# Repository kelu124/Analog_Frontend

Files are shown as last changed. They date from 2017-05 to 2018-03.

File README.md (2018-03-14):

# Analog Frontend PCB
This folder contains the design files for the analog circuitry required for a single channel of an ultrasound imaging system. 

Schematic:  
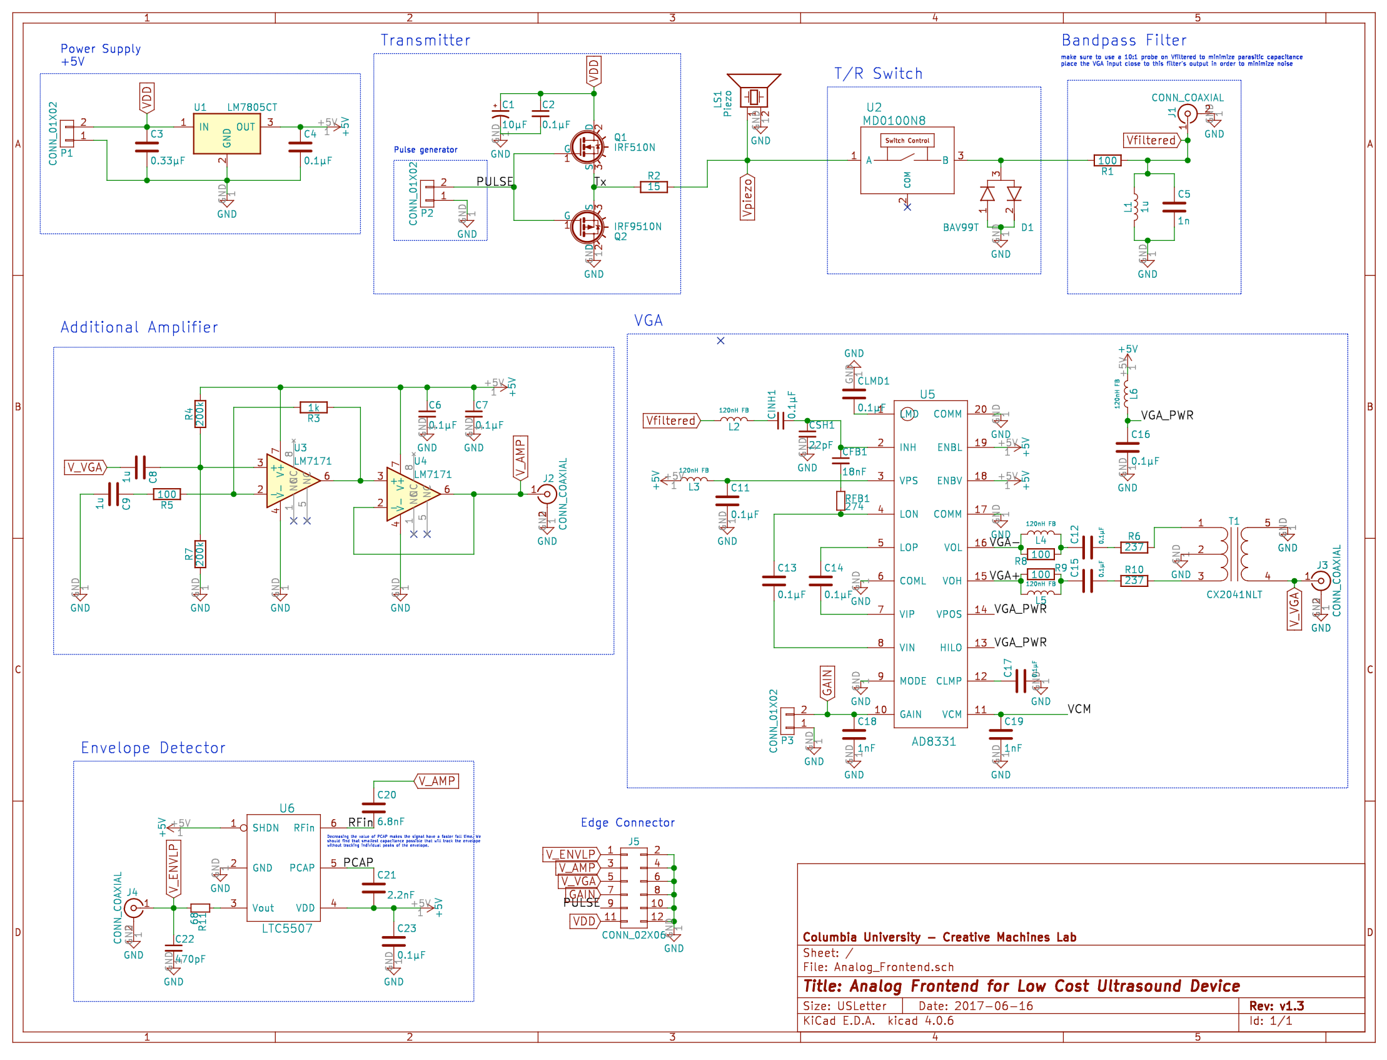
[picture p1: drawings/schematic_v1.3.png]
Schematic
  
See the `drawings` folder for a high-resolution PDF version.

PCB:  
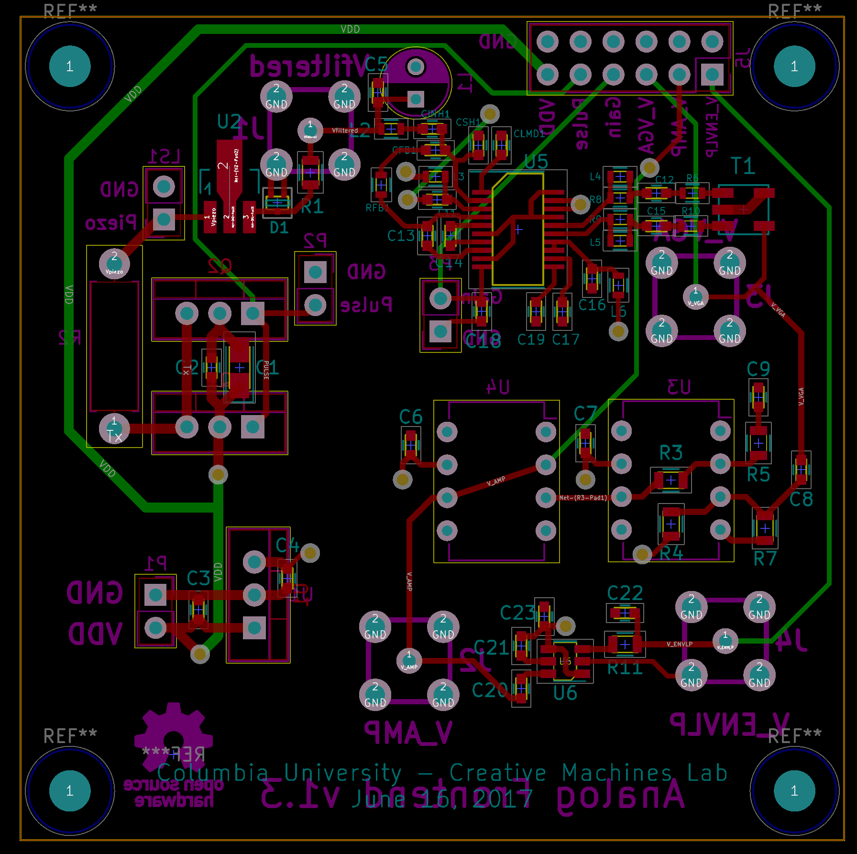
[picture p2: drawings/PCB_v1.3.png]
PCB
  
See the `drawings` folder for a full resolution PDF version, including each layer individually.

### Bill of Materials
See `Analog_Frontend.html`.

### Changelog
* `v1.0` Initial design
* `v1.1` 
* `v1.2` 
* `v1.3` Added a row of header pins and silkscreened labels
* `v1.3-doc` Added documentation
* `v2.0` Minitiarized design
* `v2.1b` Single transistor transmitter
* `v2.2_op1` Single transistor transmitter with higher output power
* `v2.2_op2` Push-pull transmitter using DMN2004K and DMP2004K MOSFETs
* `v2.2_op3` (Work in Progress) Transmitter using the MD1213 and TC6320 ultrasound transmitter chips

Each version can be accessed in this repository through the git tag system. 

### Credits
Designed by William Meng, Cindy Xiao, and Ruoyu Sheng.

The VGA subcircuit design was adapted from the [AD8331 evaluation board](http://www.analog.com/media/en/technical-documentation/evaluation-documentation/154207235AD8331EB_a.pdf). 

Community-developed KiCAD symbols and models:

* [SMA footprint](https://github.com/rascalmicro/rascalmicro-kicad-footprints.pretty/blob/master/SMA.kicad_mod)
* [SOT-523 footprint](https://github.com/cpavlina/kicad-pcblib/blob/master/smd-semi.pretty/SOT-523.kicad_mod)
* [Teensy symbols](https://github.com/XenGi/teensy_library) and [Teensy footprints](https://github.com/XenGi/teensy.pretty)

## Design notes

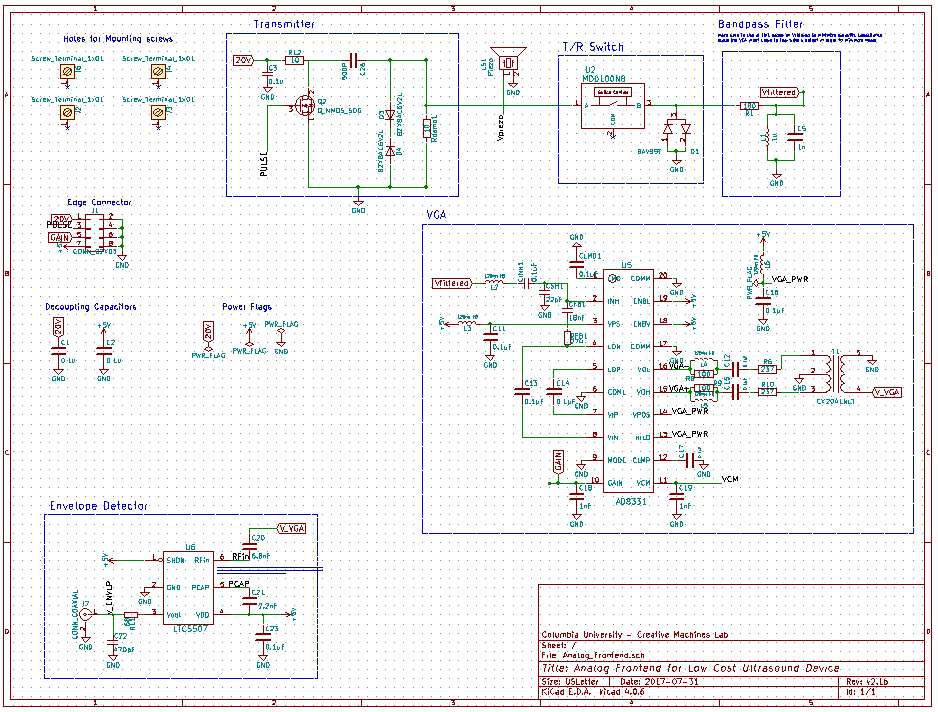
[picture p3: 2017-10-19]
drawings/schematic_v2.1b.PNG

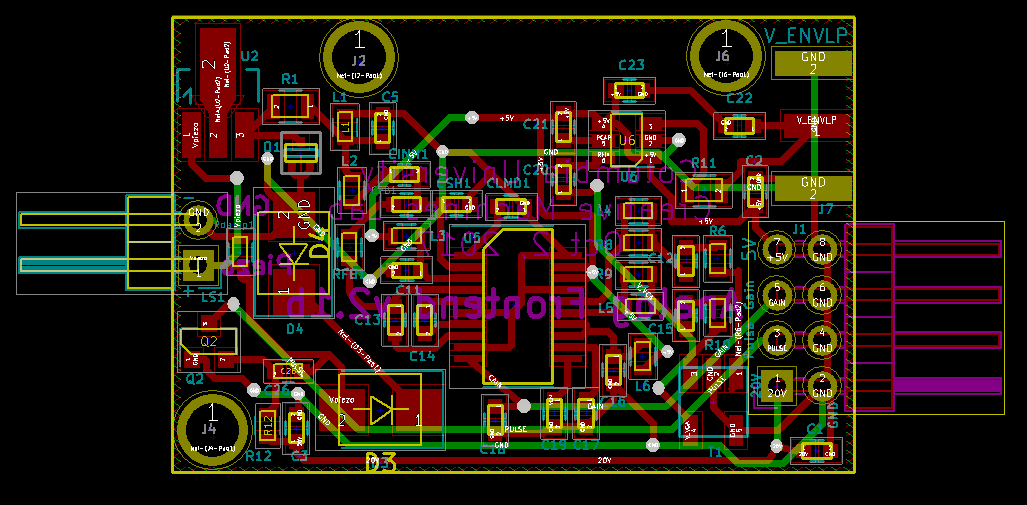
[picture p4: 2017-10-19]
drawings/PCB_v2.1b.png

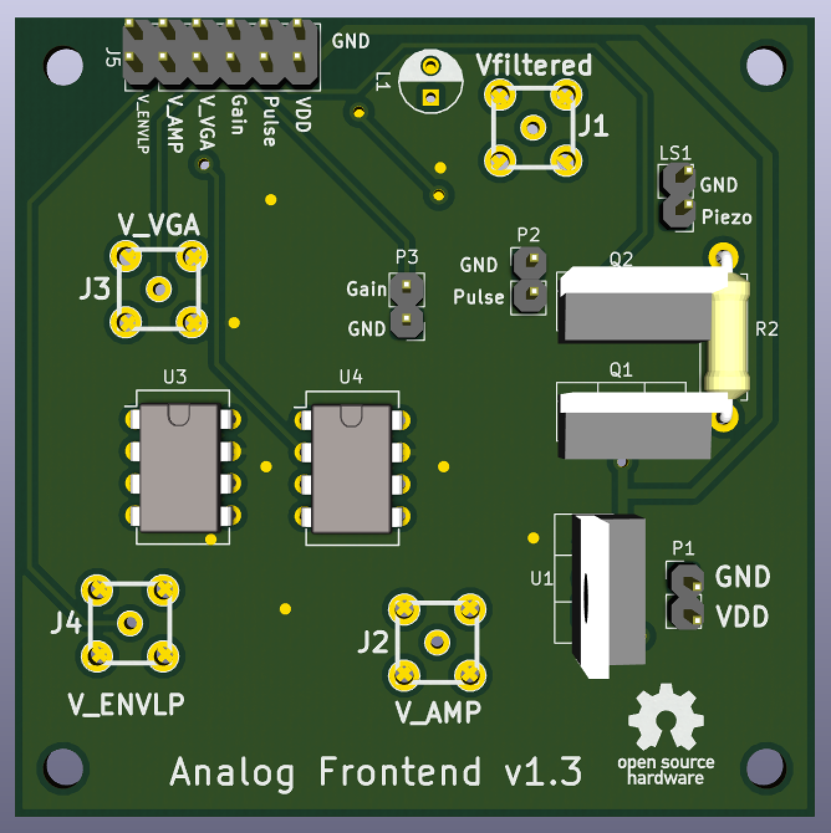
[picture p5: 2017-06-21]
drawings/PCB_back3D_v1.3.png

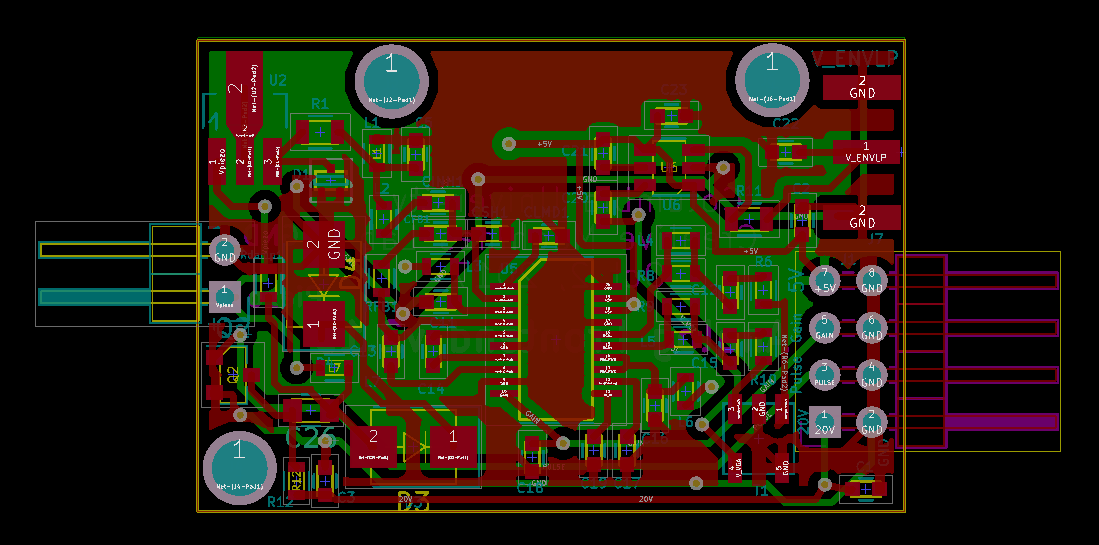
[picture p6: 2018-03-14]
drawings/PCB_v2.2_op1.png

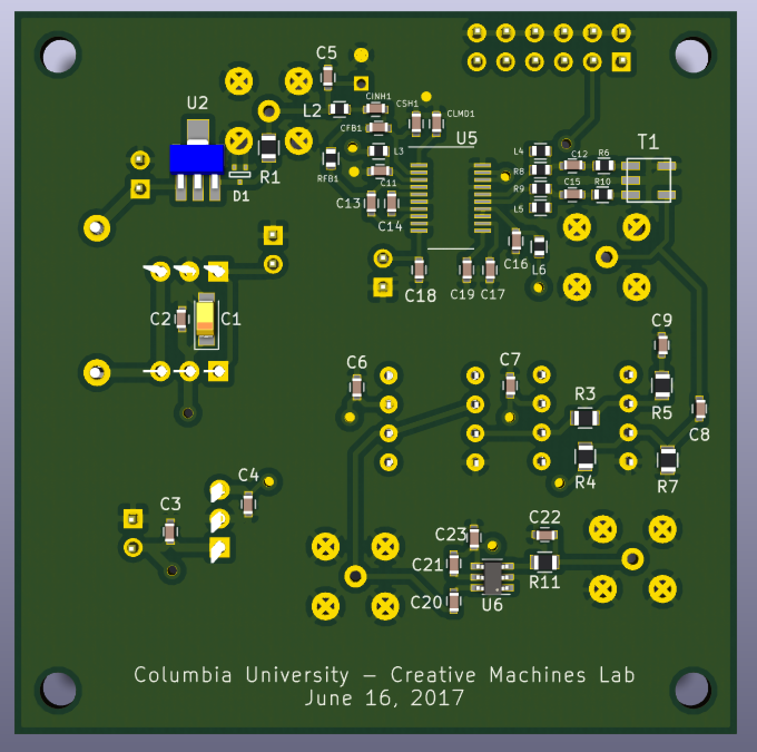
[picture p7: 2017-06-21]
drawings/PCB_front3D_v1.3.png

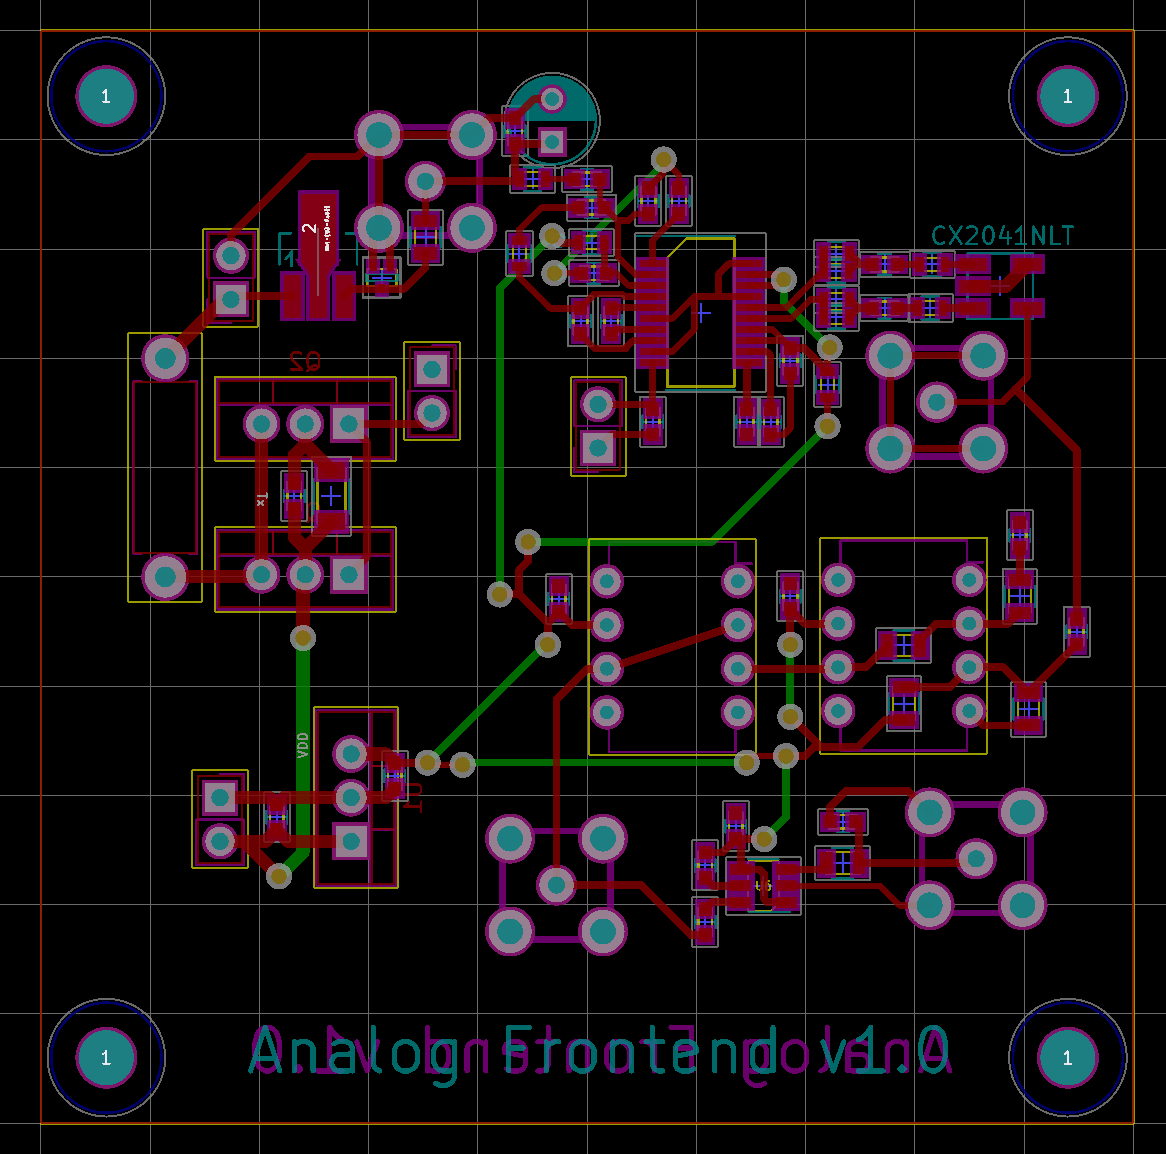
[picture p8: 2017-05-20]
drawings/PCB.png

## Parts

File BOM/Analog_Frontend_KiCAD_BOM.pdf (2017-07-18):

Ref | Qty | Value | Footprint
C5 | 1 | 1n | Capacitors_SMD:C_0603
C21 | 1 | 2.2nF | Capacitors_SMD:C_0603
C20 | 1 | 6.8nF | Capacitors_SMD:C_0603
C8 C9 | 2 | 1u | Capacitors_SMD:C_0603
C14 C13 C16 C11 C12 C15 C17 C23 C4 C2 CLMD1 CINH1 C7 C6 | 14 | 0.1ÂµF | Capacitors_SMD:C_0603
C18 C19 | 2 | 1nF | Capacitors_SMD:C_0603
C3 | 1 | 0.33ÂµF | Capacitors_SMD:C_0603
C1 | 1 | 10ÂµF | Capacitors_Tantalum_SMD:CP_Tantalum_Case- A_EIA-3216- 18_Reflow
C22 | 1 | 470pF | Capacitors_SMD:C_0603
CFB1 | 1 | 18nF | Capacitors_SMD:C_0603
CSH1 | 1 | 22pF | Capacitors_SMD:C_0603
D1 | 1 | BAV99T | custom:SOT-523
J3 J1 J4 J2 | 4 | CONN_COAXIAL | custom:SMA_uxcell
J5 | 1 | CONN_02X06 | Pin_Headers:Pin_Header_Straight_2x06_Pitch2.54mm
L1 | 1 | 1u | Capacitors_THT:C_Radial_D5_L6_P2.5
L6 L3 L2 L4 L5 | 5 | 120nH FB | Resistors_SMD:R_0603

# ANALOG FRONTEND FOR LOW COST ULTRASOUND DEVICE BOM REV V1.3

DATE

2017-06-16

COMPANY

Columbia University - Creative Machines Lab

COMMENT 1 | COMMENT 2
COMMENT 3 | COMMENT 4 | TOTAL PARTS
| | 63 (Unique 34)

# [C] - Capacitors

# [CFB] -

# [CSH] -

# [D] - Diodes

[J] -

# [L] - Inductors

LS1 | 1 | Piezo | Pin_Headers:Pin_Header_Straight_1x02_Pitch2.54mm
P2 P1 P3 | 3 | CONN_01X02 | Pin_Headers:Pin_Header_Straight_1x02_Pitch2.54mm
Q1 | 1 | IRF510N | TO_SOT_Packages_THT:TO- 220_Vertical
Q2 | 1 | IRF9510N | TO_SOT_Packages_THT:TO- 220_Vertical
R2 | 1 | 15 | Resistors_THT:R_Axial_DIN0411_L9.9mm_D3.6mm_P12.70mm_Horizontal
R1 R5 | 2 | 100 | Resistors_SMD:R_0805
R4 R7 | 2 | 200k | Resistors_SMD:R_0805
R3 | 1 | 1k | Resistors_SMD:R_0805
R8 R9 | 2 | 100 | Resistors_SMD:R_0603
R6 R10 | 2 | 237 | Resistors_SMD:R_0603
R11 | 1 | 68 | Resistors_SMD:R_0805
RFB1 | 1 | 274 | Resistors_SMD:R_0603
T1 | 1 | CX2041NLT | custom:CX2041NLT
U6 | 1 | LTC5507 | custom:TSOT-23- 6_MK06A
U5 | 1 | AD8331 | custom:QSOP- 20_3.9x8.6mm_Pitch0.64mm
U1 | 1 | LM7805CT | TO_SOT_Packages_THT:TO- 220_Vertical
U3 U4 | 2 | LM7171 | Housings_DIP:DIP- 8_W7.62mm
U2 | 1 | MD0100N8 | TO_SOT_Packages_SMD:SOT89- 3_Housing_Handsoldering

[LS] -

# [P] - Connectors

# [Q] - Transistors

# [R] - Resistors

# [RFB] -

[T] -

# [U] - Semiconductors

BOM made with KICAD_BOM_WIZARD (Generated Tuesday, July 18, 2017 'AMt' 11:46:00 AM)

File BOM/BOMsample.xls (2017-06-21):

Mfg Part # | Ref Des | Manufacturer | Dist. Part # | Qty | Description
06031C102KAT2A | C5,C18，C19 | AVX Corporation | 478-1199-1-ND | 3 | CAP CER 1000PF 100V X7R 0603
C0603C682F3GACTU | C20 | KEMET | 399-11154-2-ND | 1 | CAP CER 6800PF 25V C0G/NP0 0603
0603ZC105JAT2A | C8C9 | AVX Corporation | 478-10074-2-ND | 2 | CAP CER 1UF 10V X7R 0603
06035C104KAZ2A | C14，C13，C16，C11，C12，C15，C17,C23，C4，C2，CLMD1.C1NH1，C7，C6 | AVX Corporation | 478-3540-1-ND | 14 | CAP CER 0.1UF 50V X7R 0603
C1608X7R1H334K080AC | C3 | TDK Corporation | 445-5950-1-ND | 1 | CAP CER 0.33UF 50V X7R 0603
F931A106MAA | C1 | AVX Corporation | 478-8193-1-ND | 1 | CAP TANT 10UF 10V 20% 1206
C1608C0G1H471F080AA | C22 | TDK Corporation | 445-5370-2-ND | 1 | CAP CER 470PF 50V C0G 0603
C0603C183K5RACTU | CFB1 | KEMET | 399-7868-1-ND | 1 | CAP CER 0.018UF 50V X7R 0603
06035A220JAT2A | CSH1 | AVX Corporation | 478-1167-1-ND | 1 | CAP CER 22PF 50V C0G/NP0 0603
BAV99T-7-F | D1 | Diodes Incorporated | BAV99T-FDICT-ND | 1 | DIODE ARRAY GP 85V 75MA SOT523
BLM18BA750SN1D | L2 L3 L4 L5 L6 | Murata Electronics North America | 490-1018-1-ND | 5 | FERRITE BEAD 75 OHM 0603 1LN
RC0805FR-07100RL | R1 R5 | Yageo | 311-100CRTR-ND | 2 | RES SMD 100 OHM 1% 1/8W 0805
RC0805FR-07200KL | R4 R7 | Yageo | 311-200KCRTR-ND | 2 | RES SMD 200K OHM 1% 1/8W 0805
RC0805FR-071KL | R3 | Yageo | 311-1.00KCRTR-ND | 1 | RES SMD 1K OHM 1% 1/8W 0805
CRG0603F100R | R8 R9 | TE Connectivity Passive Product | A106047CT-ND | 2 | RES SMD 100 OHM 1% 1/10W 0603
ERJ-3EKF2370V | R6 R10 | Panasonic Electronic Components | P237HCT-ND | 2 | RES SMD 237 OHM 1% 1/10W 0603
RC0805FR-0768RL | R11 | Yageo | 311-68.0CRTR-ND | 1 | RES SMD 68 OHM 1% 1/8W 0805
ERJ-3EKF2740V | RFB1 | Panasonic Electronic Components | P274HCT-ND | 1 | RES SMD 274 OHM 1% 1/10W 0603
CX2041NLT | T1 | Pulse Electronics Corporation | 553-2290-2-ND | 1 | TRANSFORMER FOR WIDEBAND RF APP
LTC5507ES6#TRMPBF | U6 | Linear Technology | LTC5507ES6#TRMPBFCT-ND | 1 | IC DETEC RF 100KHZ-1GHZ TSOT23-6
AD8331ARQZ-R7 | U5 | Analog Devices |  | 1 | SP Amp Variable Gain Amp Single 5.5V 20-Pin QSOP T/R
MD0100N8-G | U2 | Microchip Technology | MD0100N8-GCT-ND | 1 | IC PWM MGMT SUPERVISOR SOT89-3
GRM1885C1H222FA01D | C21 | Murata Electronics North America | 490-7768-2-ND | 1 | CAP CER 2200PF 50V C0G/NP0 0603
11R102C | L1 | Murata Power Solutions Inc. | 811-2018-ND | 1 | FIXED IND 1UH 3A 20 MOHM TH
IRF510PBF | Q1 | Vishay Siliconix | IRF510PBF-ND | 1 | MOSFET N-CH 100V 5.6A TO-220AB
IRF9510PBF | Q2 | Vishay Siliconix | IRF9510PBF-ND | 1 | MOSFET P-CH 100V 4A TO-220AB
CF14JT15R0 | R2 | Stackpole Electronics Inc. | CF14JT15R0TR-ND | 1 | RES 15 OHM 1/4W 5% AXIAL
LM7805ACT | U1 | Fairchild/ON Semiconductor | LM7805ACT-ND | 1 | IC REG LDO 5V 1A TO220-3
LM7171BIN/NOPB | U3 U4 | Texas Instruments | LM7171BIN/NOPB-ND | 2 | IC OPAMP VFB 200MHZ 8DIP
 | J1, J2, J3, J4 |  |  | 4 | JUMP

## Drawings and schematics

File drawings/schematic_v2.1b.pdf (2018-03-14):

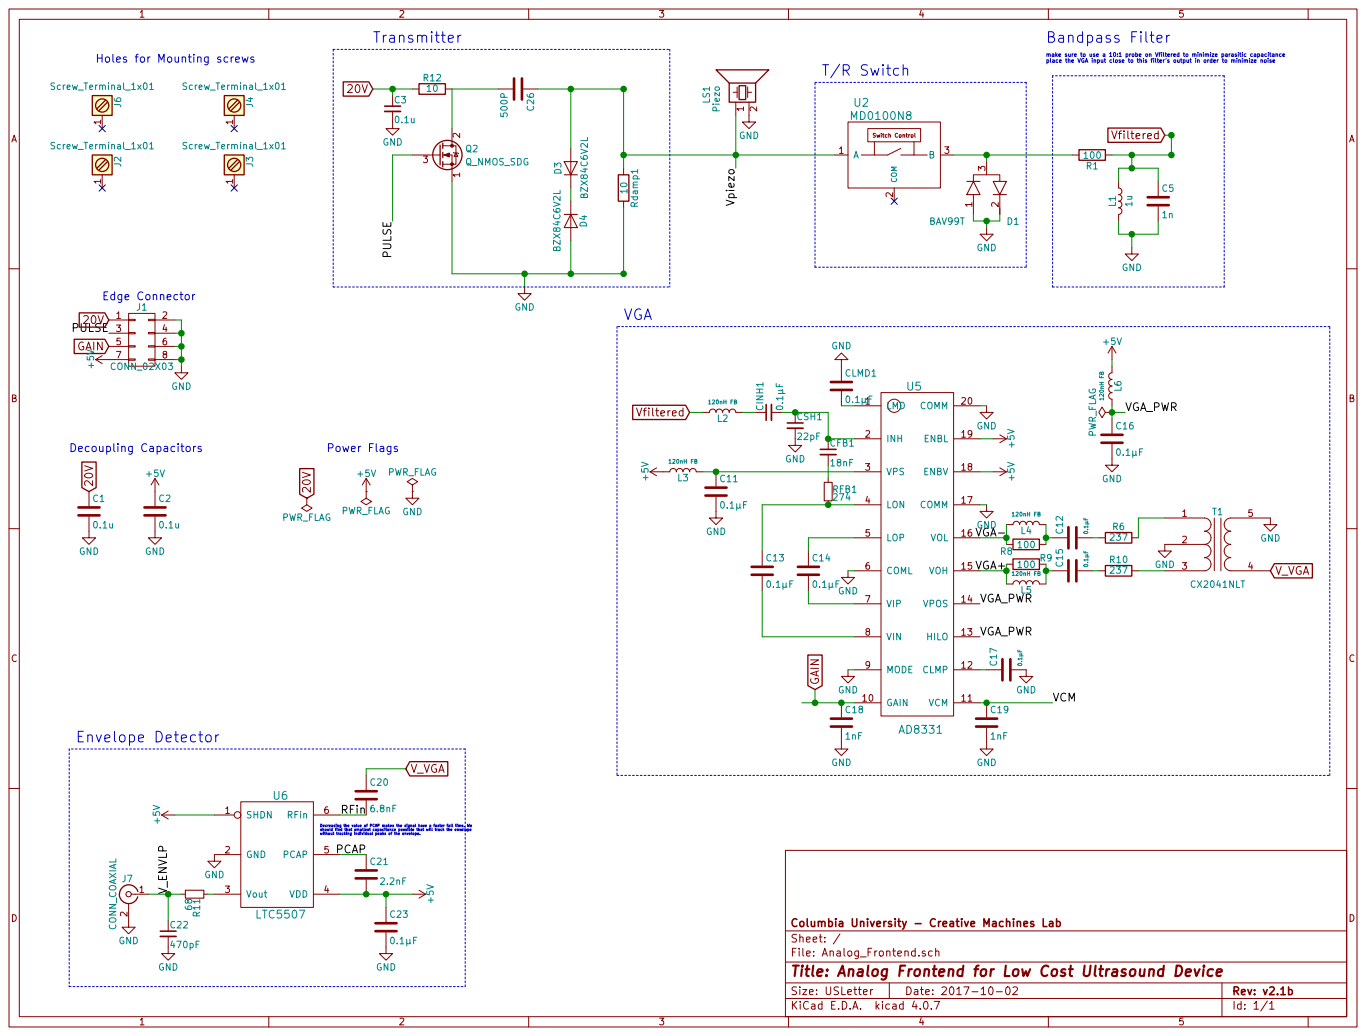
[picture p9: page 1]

make sure to use a 10:1 probe on Vfiltered to minimize parasitic capacitance
place the VGA input close to this filter's output in order to minimize noise

Decreasing the value of PCAP makes the signal have a faster fall time. We should find that smallest capacitance possible that will track the envelope without tracking individual peaks of the envelope. PULSE
GAIN

File: Analog_Frontend.sch Sheet: / Columbia University - Creative Machines Lab

Id: 1/1 Title: Analog Frontend for Low Cost Ultrasound Device

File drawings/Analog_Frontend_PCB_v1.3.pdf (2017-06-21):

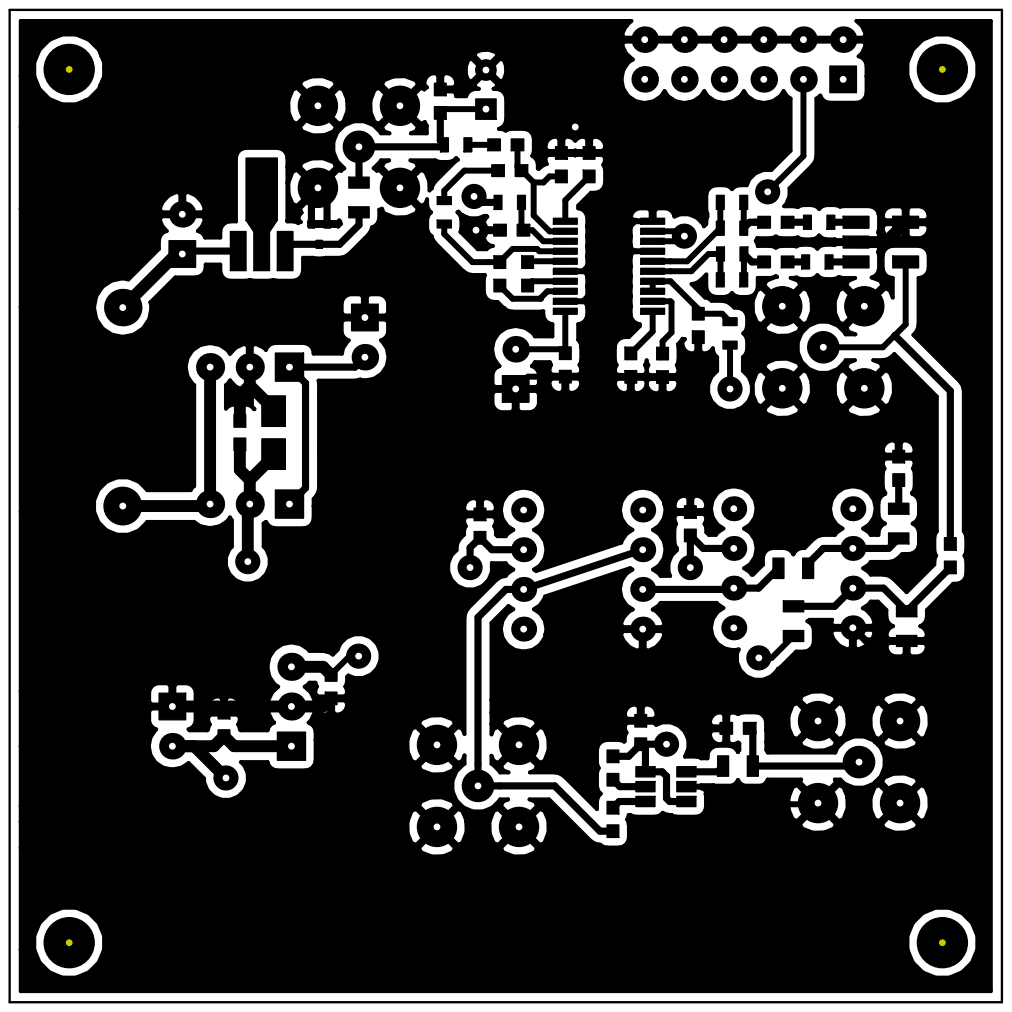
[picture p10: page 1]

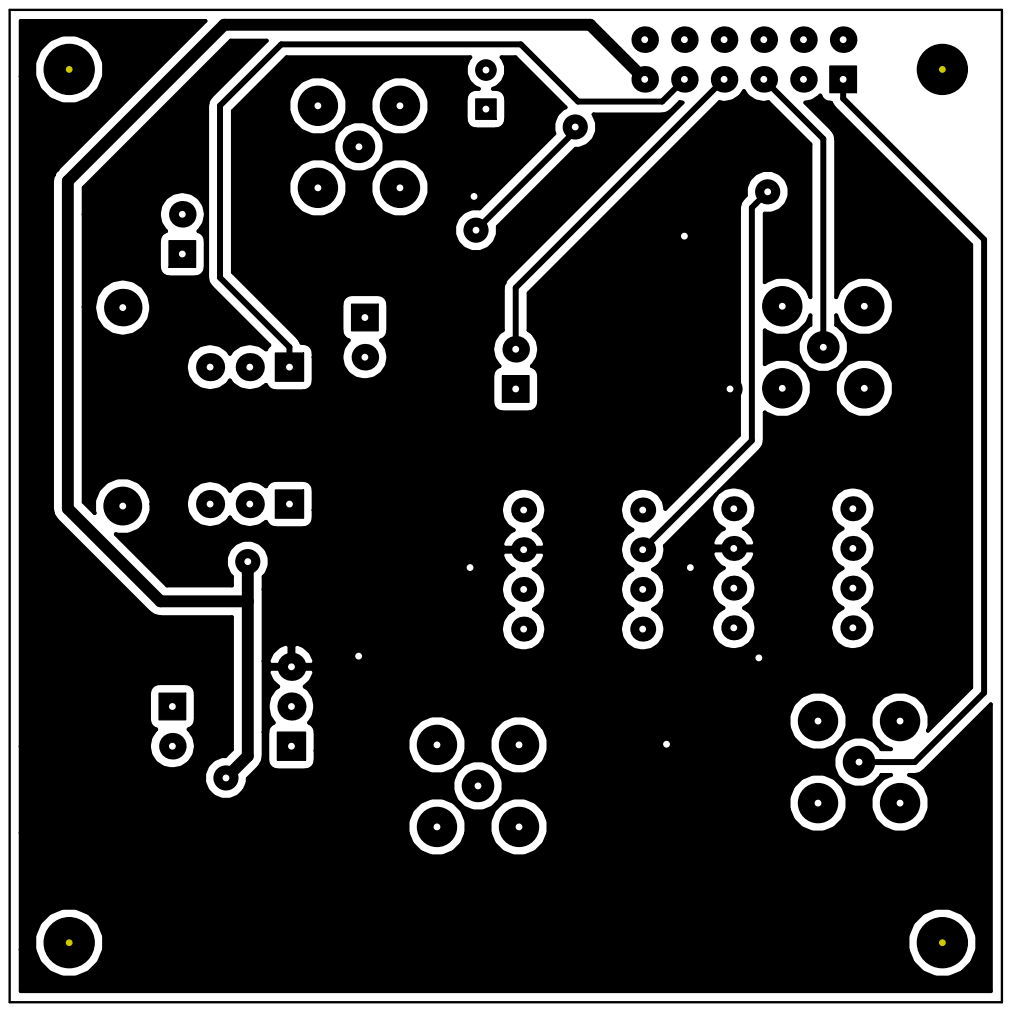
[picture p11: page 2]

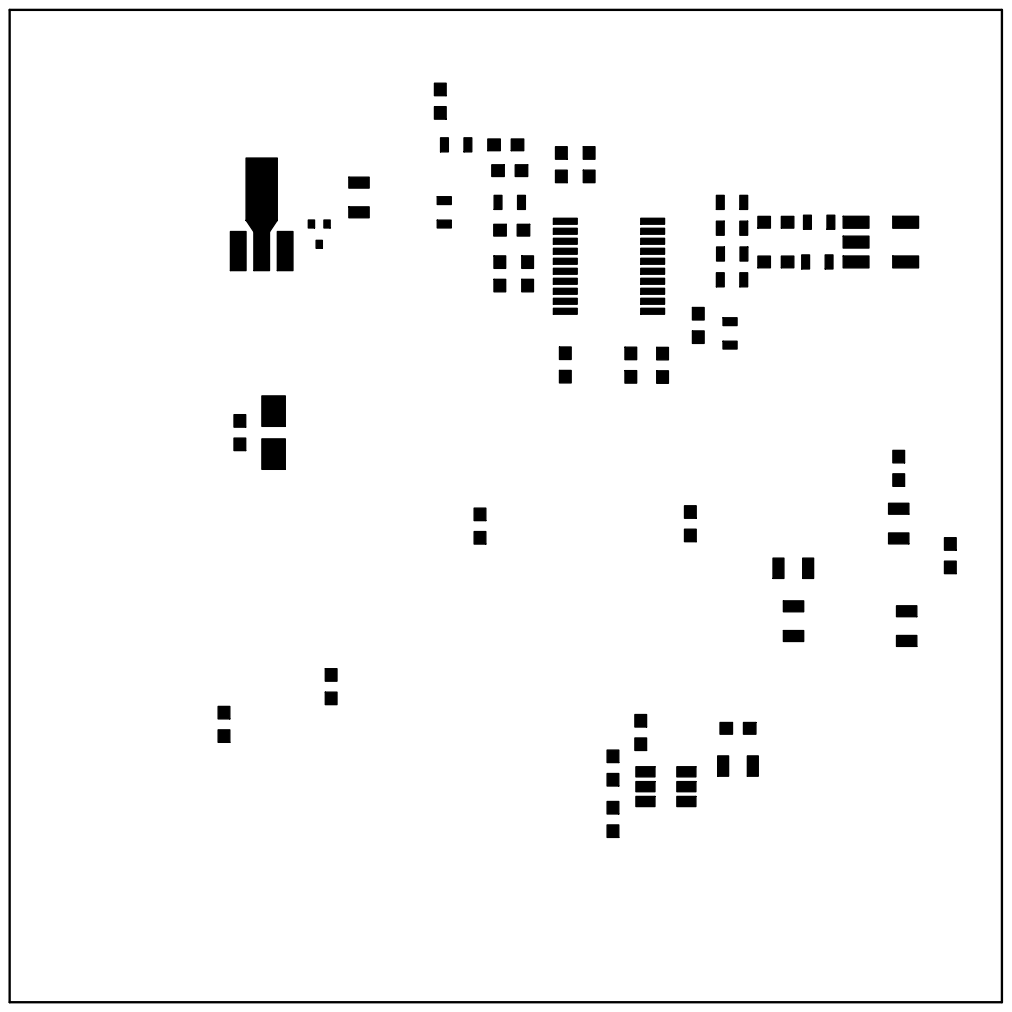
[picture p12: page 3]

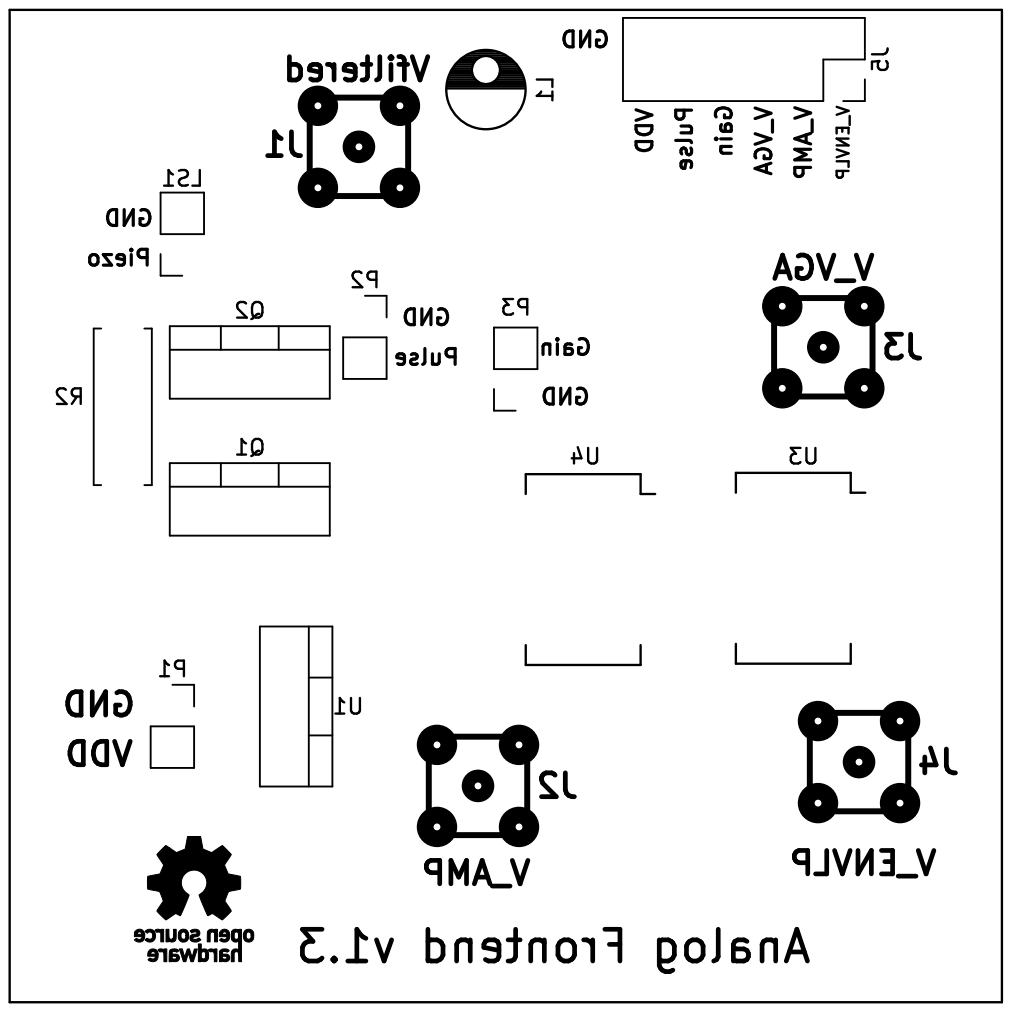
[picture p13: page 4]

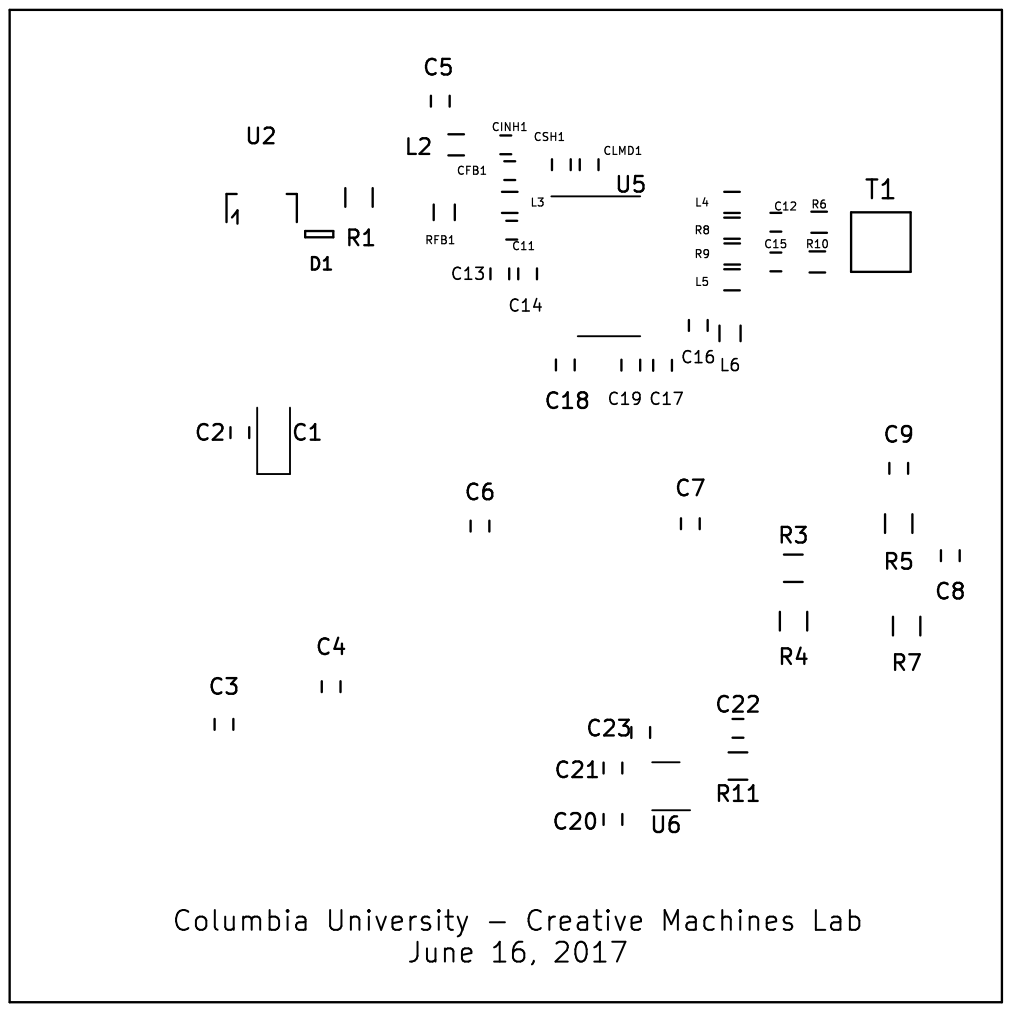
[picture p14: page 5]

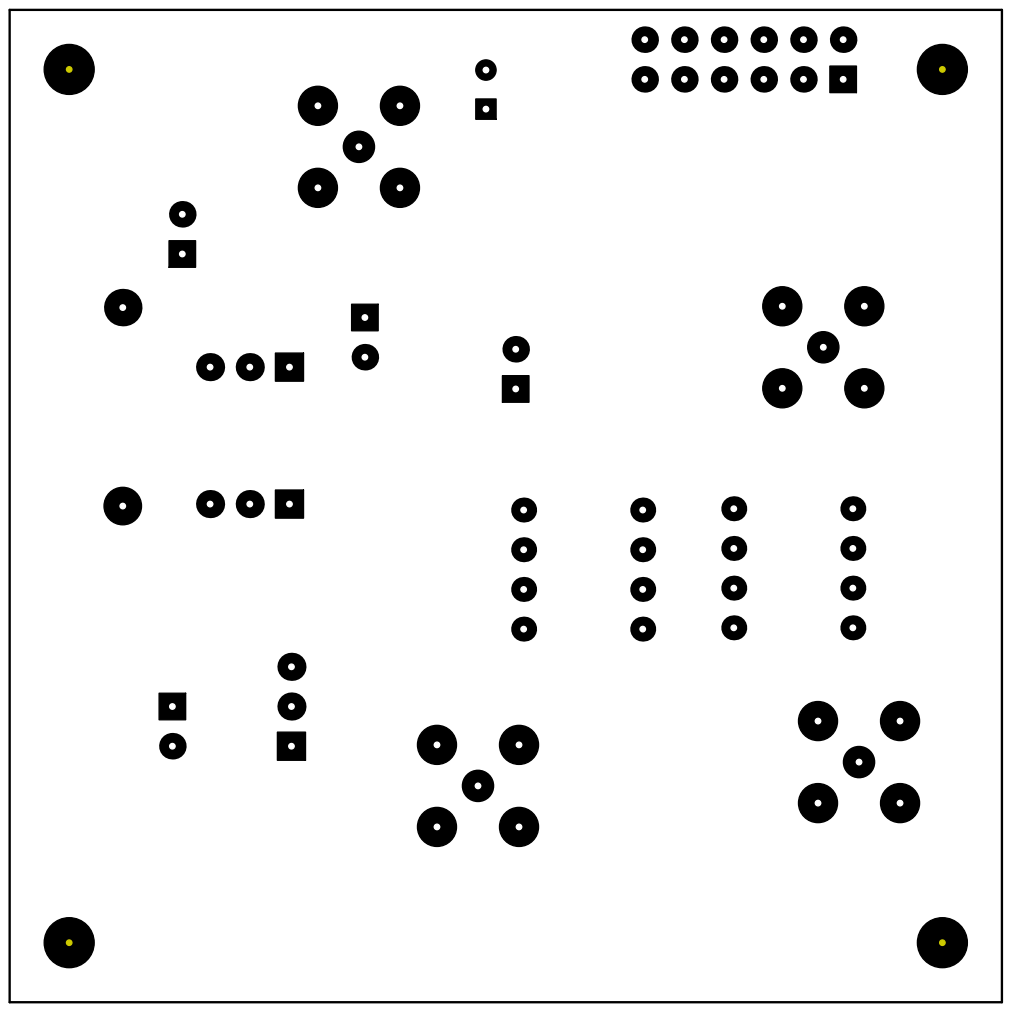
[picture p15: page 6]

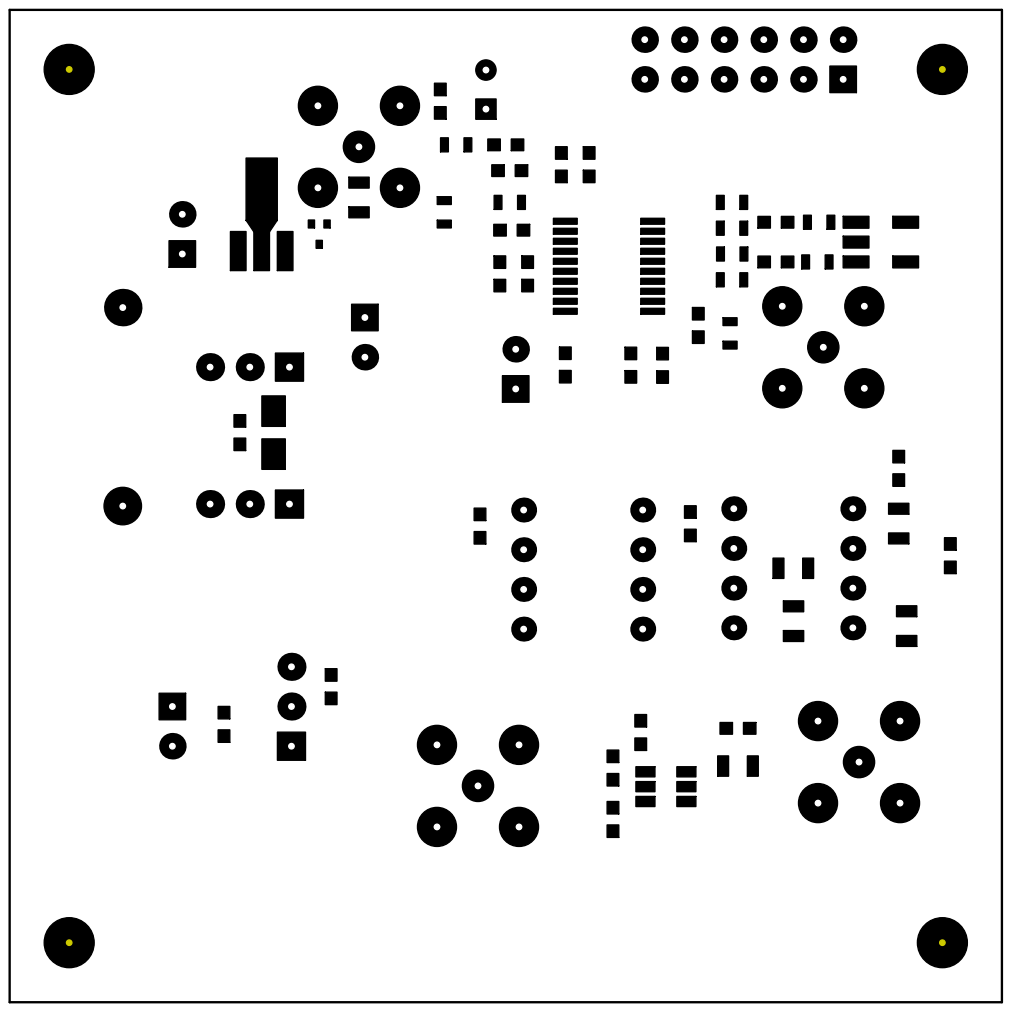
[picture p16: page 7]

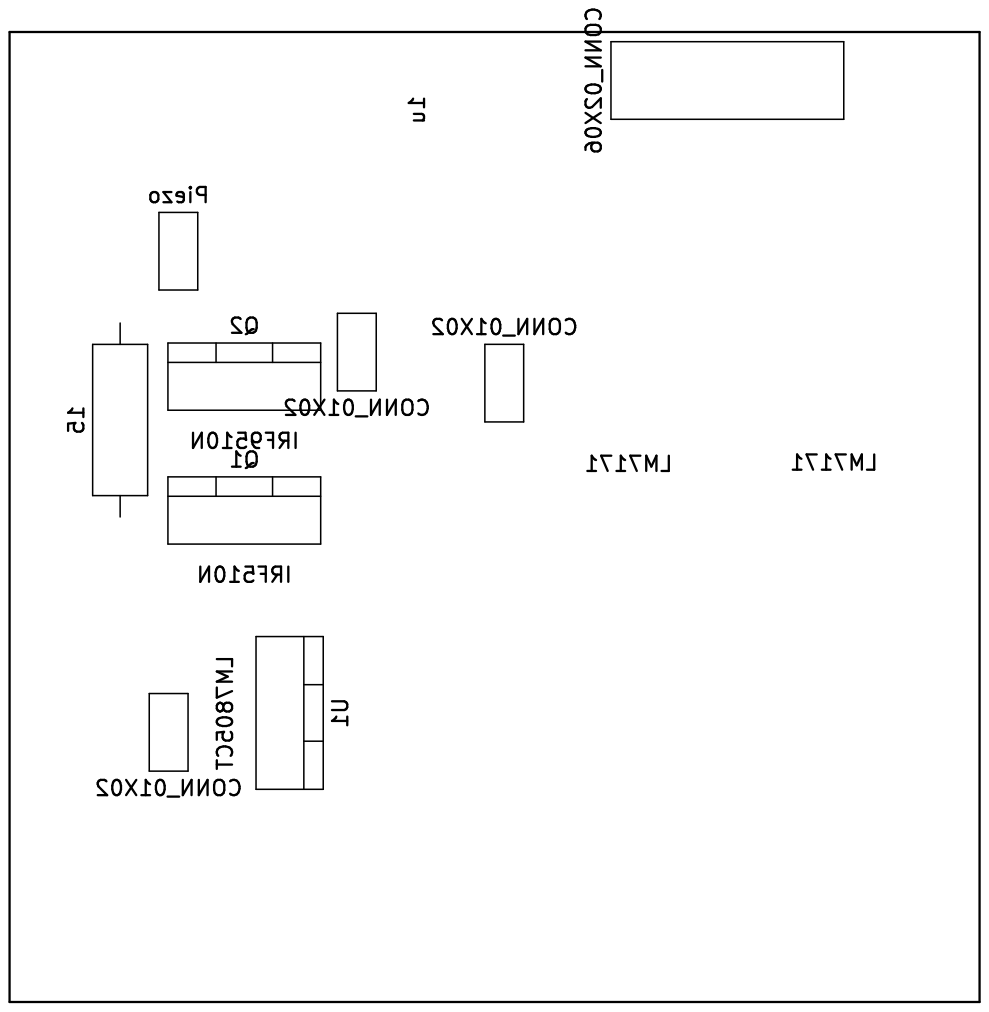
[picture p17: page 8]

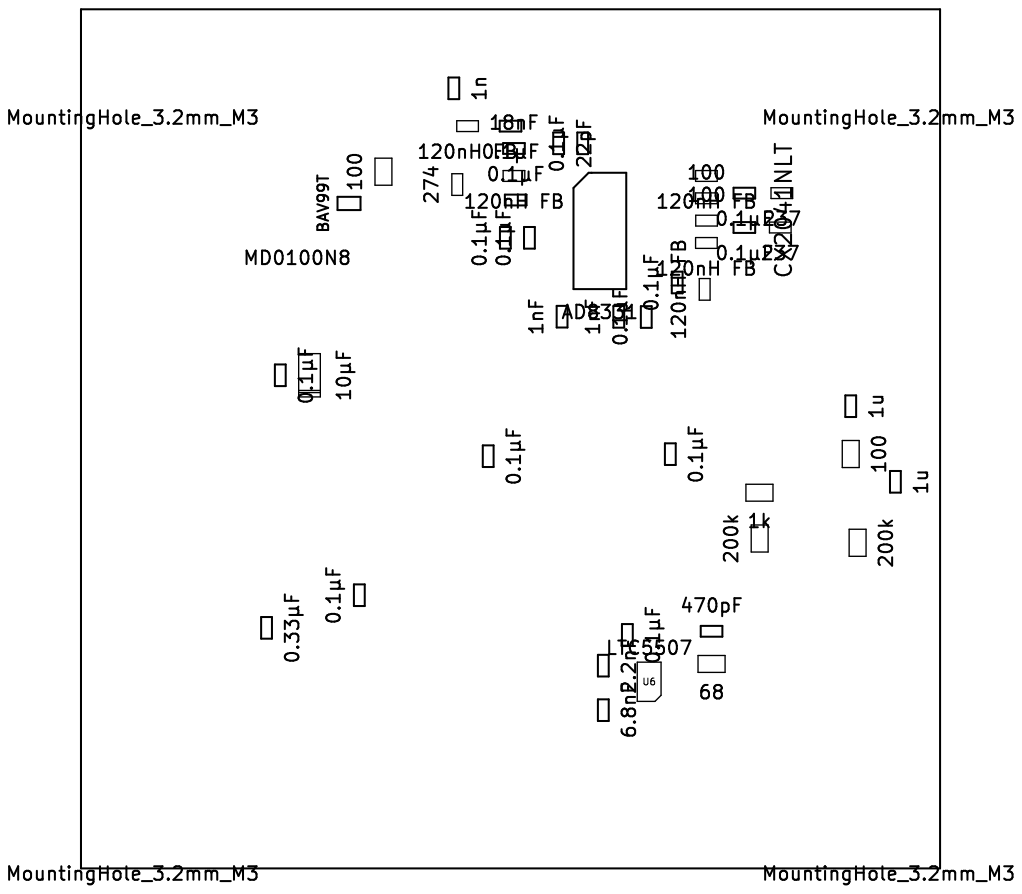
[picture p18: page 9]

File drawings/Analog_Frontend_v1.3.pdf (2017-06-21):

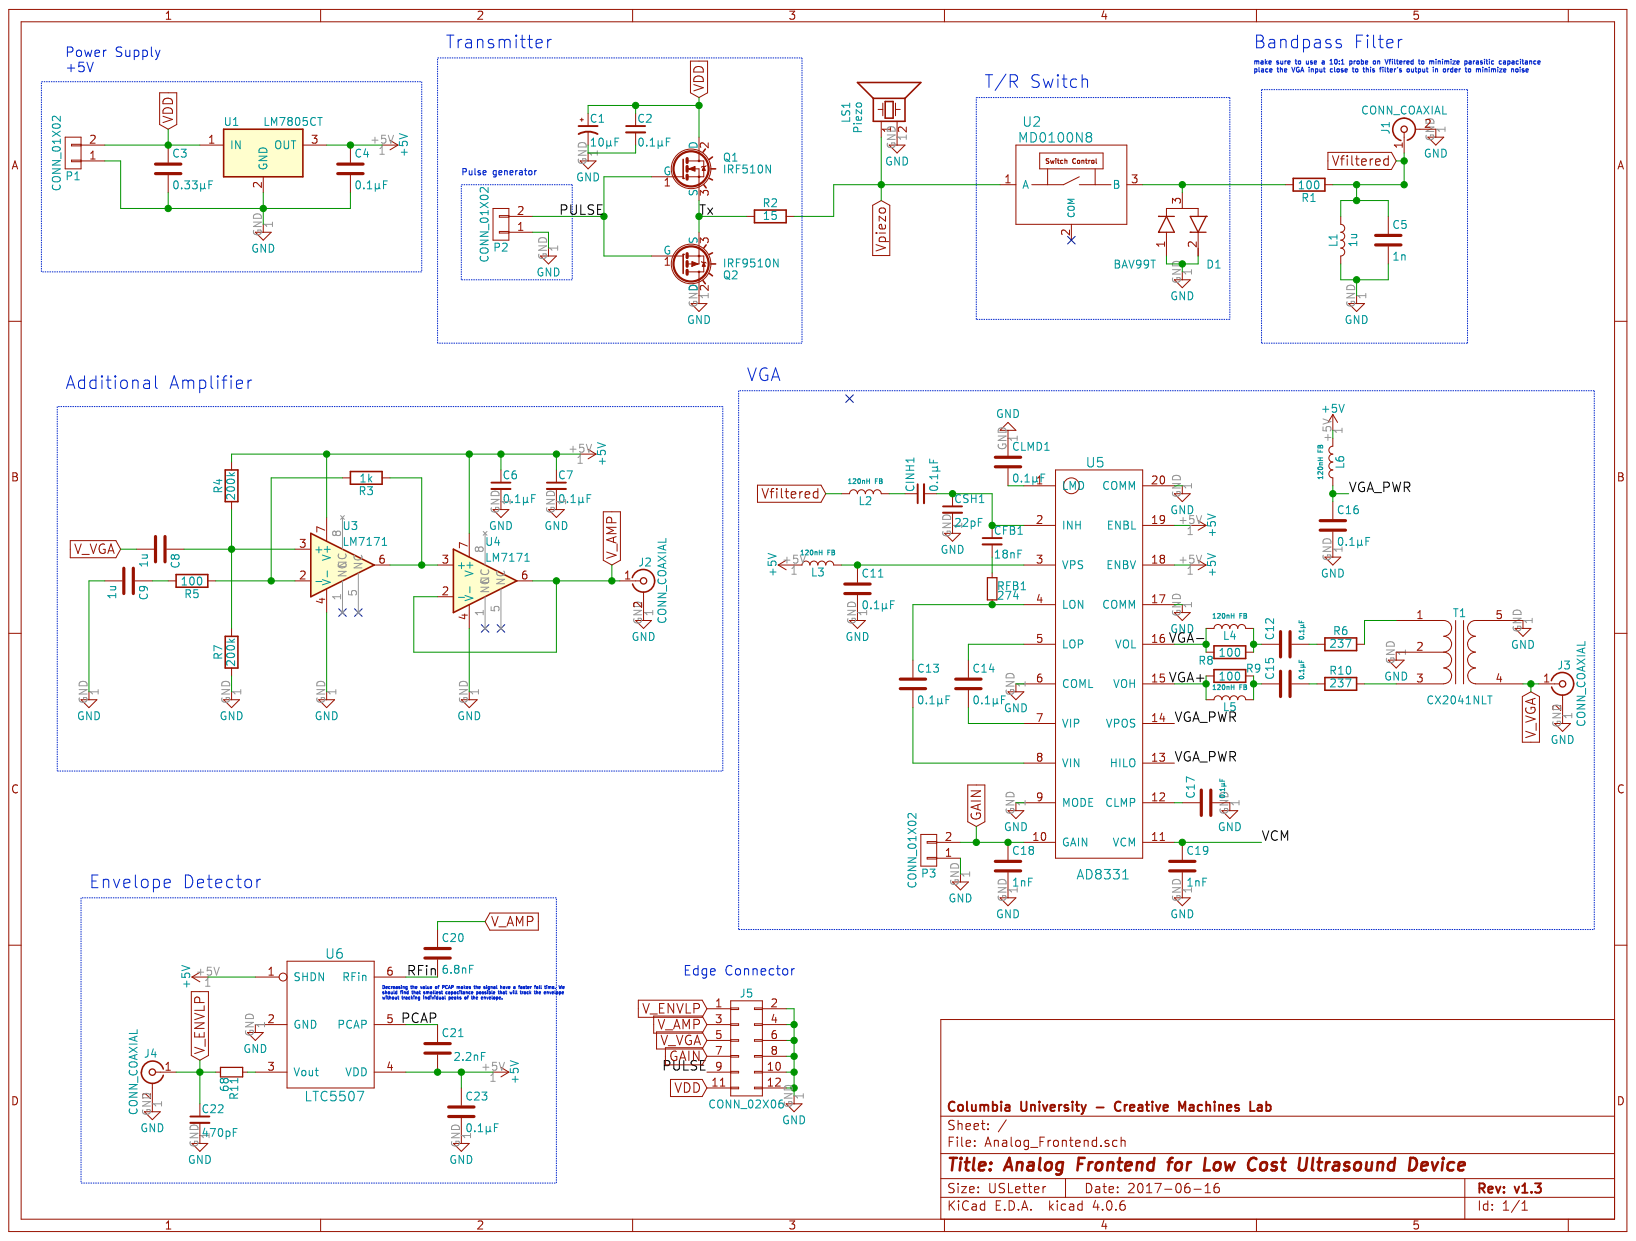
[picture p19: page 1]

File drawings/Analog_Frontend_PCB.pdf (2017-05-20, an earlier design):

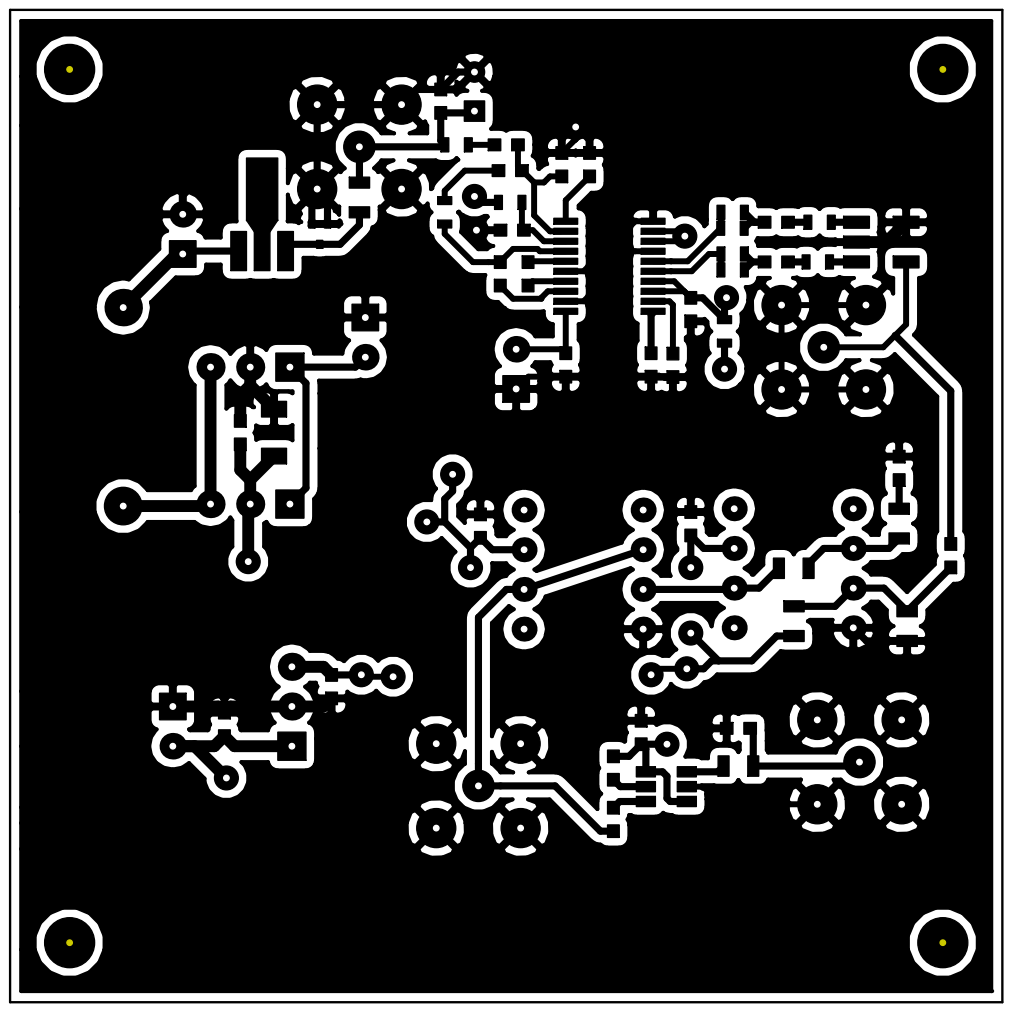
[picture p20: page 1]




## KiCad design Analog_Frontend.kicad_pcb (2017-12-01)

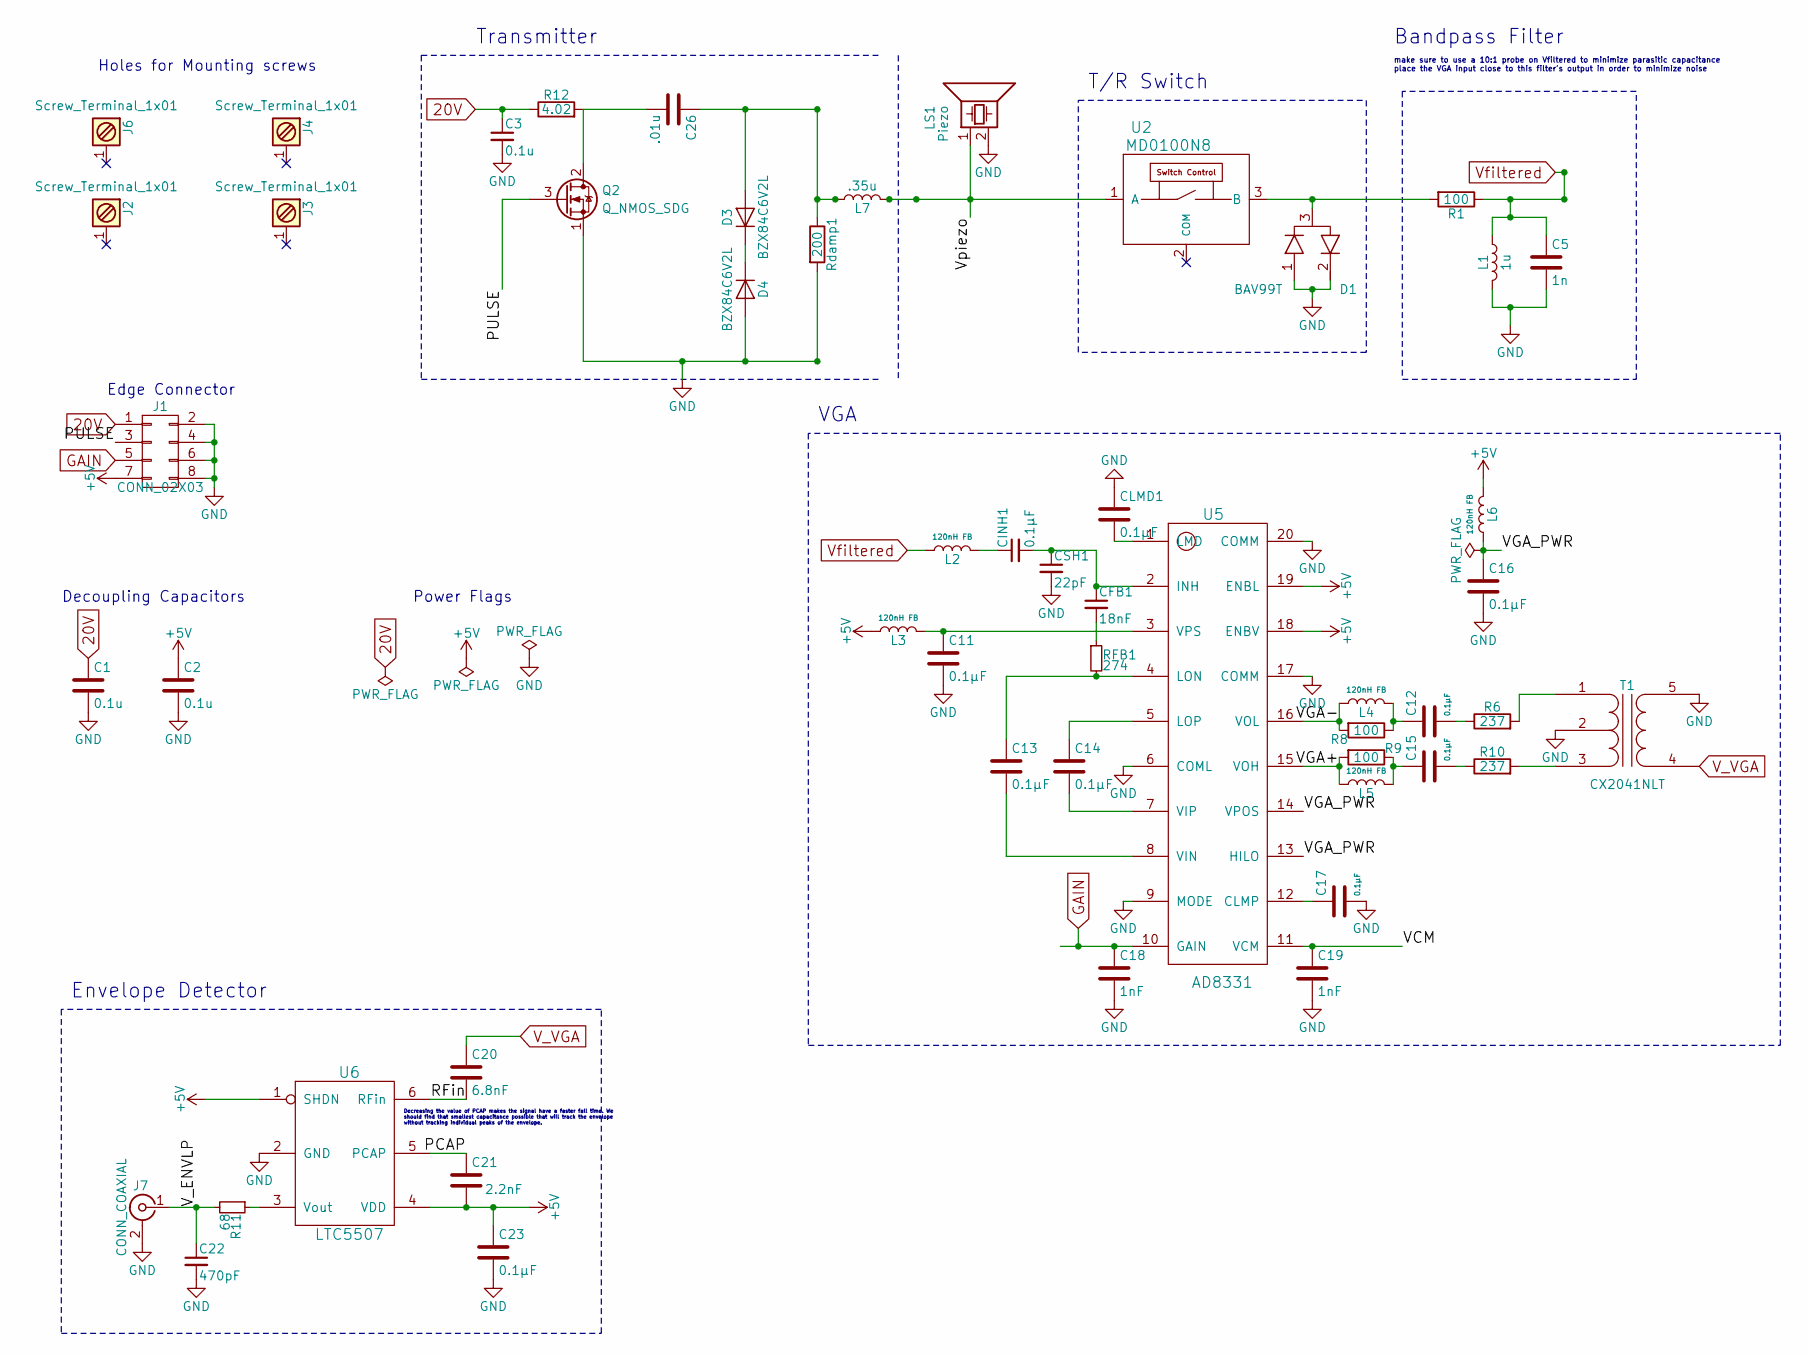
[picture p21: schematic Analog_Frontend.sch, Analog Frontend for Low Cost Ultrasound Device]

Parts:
C1, C2, C3: 0.1u; C_0603
C5: 1n; C_0603
C11, C12, C13, C14, C15, C16, C17, C23: 0.1µF; C_0603
C18, C19: 1nF; C_0603
C20: 6.8nF; C_0603
C21: 2.2nF; C_0603
C22: 470pF; C_0603
C26: .01u; C_0805
CFB1: 18nF; C_0603
CINH1: 0.1µF; C_0603
CLMD1: 0.1µF; C_0603
CSH1: 22pF; C_0603
D1: BAV99T; SOT-523
D3, D4: BZX84C6V2L; D_SMB
J1: CONN_02X03; Pin_Header_Angled_2x04_Pitch2.54mm
J2, J3, J4, J6: Screw_Terminal_1x01; SCREWM3
J7: CONN_COAXIAL; SAM8857-ND
L1: 1u; L_0603
L2, L3, L4, L5, L6: 120nH FB; R_0603
L7: .35u; L_0603
LS1: Piezo; Pin_Header_Angled_1x02_Pitch2.54mm
Q2: Q_NMOS_SDG; SOT-23
R1: 100; R_0805
R6, R10: 237; R_0603
R8, R9: 100; R_0603
R11: 68; R_0805
R12: 4.02; R_0603
RFB1: 274; R_0603
Rdamp1: 200; R_0603
T1: CX2041NLT
U2: MD0100N8; SOT89-3_Housing_Handsoldering
U5: AD8331; QSOP-20_3.9x8.6mm_Pitch0.64mm
U6: LTC5507; TSOT-23-6_MK06A

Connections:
20V: C1.1, C3.1, J1.1, R12.1
+5V: C2.1, C21.2, C23.1, J1.7, L3.1, L6.2, U5.18 (ENBV), U5.19 (ENBL), U6.1 (SHDN), U6.4 (VDD)
/PCAP: C21.1, U6.5 (PCAP)
/PULSE: J1.3, Q2.3 (G)
/RFin: C20.2, U6.6 (RFin)
/VCM: C19.1, U5.11 (VCM)
/VGA+: L5.1, R9.2, U5.15 (VOH)
/VGA-: L4.1, R8.2, U5.16 (VOL)
/VGA_PWR: C16.1, L6.1, U5.13 (HILO), U5.14 (VPOS)
/V_ENVLP: C22.1, J7.1 (In), R11.2
/Vpiezo: L7.2, LS1.1, U2.1 (A)
GAIN: C18.1, J1.5, U5.10 (GAIN)
GND: C1.2, C2.2, C3.2, C5.2, C11.2, C16.2, C17.2, C18.2, C19.2, C22.2, C23.2, CLMD1.1, CSH1.2, D1.1 (A), D1.2 (K), D4.2 (A), J1.2, J1.4, J1.6, J1.8, J7.2 (Ext), L1.2, LS1.2, Q2.1 (S), Rdamp1.2, T1.2 (PM), T1.5 (S2), U5.6 (COML), U5.9 (MODE), U5.17 (COMM), U5.20 (COMM), U6.2 (GND)
unnamed: C11.1, L3.2, U5.3 (VPS)
unnamed: C12.1, L4.2, R8.1
unnamed: C12.2, R6.1
unnamed: C13.1, RFB1.2, U5.4 (LON)
unnamed: C13.2, U5.8 (VIN)
unnamed: C14.1, U5.5 (LOP)
unnamed: C14.2, U5.7 (VIP)
unnamed: C15.1, L5.2, R9.1
unnamed: C15.2, R10.1
unnamed: C17.1, U5.12 (CLMP)
unnamed: C26.1, D3.2 (A), L7.1, Rdamp1.1
unnamed: C26.2, Q2.2 (D), R12.2
unnamed: CFB1.1, CINH1.2, CSH1.1, U5.2 (INH)
unnamed: CFB1.2, RFB1.1
unnamed: CINH1.1, L2.2
unnamed: CLMD1.2, U5.1 (LMD)
unnamed: D1.3 (common), R1.2, U2.3 (B)
unnamed: D3.1 (K), D4.1 (K)
unnamed: R6.2, T1.1 (PR1)
unnamed: R10.2, T1.3 (PR2)
unnamed: R11.1, U6.3 (Vout)
V_VGA: C20.1, T1.4 (S1)
Vfiltered: C5.1, L1.1, L2.1, R1.1

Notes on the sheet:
make sure to use a 10:1 probe on Vfiltered to minimize parasitic capacitance place the VGA input close to this filter's output in order to minimize noise
VGA
Transmitter
Bandpass Filter
T/R Switch
Decreasing the value of PCAP makes the signal have a faster fall time. We should find that smallest capacitance possible that will track the envelope without tracking individual peaks of the envelope.
Edge Connector
Envelope Detector
Holes for Mounting screws
Decoupling Capacitors
Power Flags

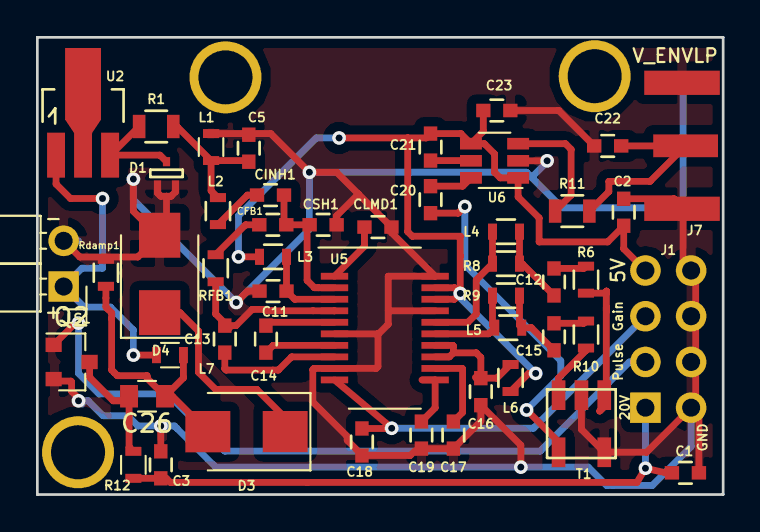
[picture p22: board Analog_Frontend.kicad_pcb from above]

Board: 2 copper layers, 38.1 x 25.4 mm, 52 parts (1 on the bottom side), 36 nets.

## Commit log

2017-05-20 Replaced spaces with underscores in folder name
    [Analog_Frontend.kicad_pcb, Analog_Frontend.sch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]
2017-06-05 Added +5V plane on B.Cu layer
    [Analog_Frontend.kicad_pcb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]
2017-06-06 Added BOM document in HTML format. See https://www.hashdefineelectronics.com/kicad-bom-wizard for instructions on how to generate this file.
2017-06-07 Added stencil file for v1.1, to be cut on Othermill with 30 degree bit
2017-06-08 Decreased value of PCAP value to speed up fall time of envelope detector.
    [Analog_Frontend.kicad_pcb, Analog_Frontend.sch]
2017-06-14 Fixed SMA footprint to match the dimensions of the SMA connectors we purchased from uxcell
    [Analog_Frontend.kicad_pcb]
2017-06-14 Removed redundant traces and vias for +5V net since we now have a +5V plane
    [Analog_Frontend.kicad_pcb]
2017-06-14 Flipped L1 to be on B.Cu layer
    [Analog_Frontend.kicad_pcb]
2017-06-15 Added some silkscreen labels
    [Analog_Frontend-B.Cu.gbr, Analog_Frontend-B.Mask.gbr, Analog_Frontend-B.Paste.gbr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]
2017-06-16 Made the silkscreened references visible and moved them around to improve readability
    [Analog_Frontend.kicad_pcb]
2017-06-16 Added 6 pin header at top of the board
    [Analog_Frontend.kicad_pcb, Analog_Frontend.sch]
2017-06-16 Cleaned up all the F.SilkS reference labels and re-routed output stage of VGA to have more spacing between components.
    [Analog_Frontend.kicad_pcb, Analog_Frontend.sch]
2017-06-16 Changed footprint of C1 from 1206 ceramic to 3216 tantalum; added OSHW logo; fixed regression with SMA connector footprints
    [Analog_Frontend.kicad_pcb, Analog_Frontend.sch]
2017-06-16 Changed solder paste clearance to -3mil
    [Analog_Frontend.kicad_pcb]
2017-06-16 PCB v1.3
    [Analog_Frontend-B.Cu.gbr, Analog_Frontend-B.Fab.gbr, Analog_Frontend-B.Mask.gbr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]
2017-06-19 Updated metadata for PCB v1.3
    [Analog_Frontend.kicad_pcb]
2017-06-21 Added documentation for everything
    [BOMsample.xls]
2017-07-18 BOM for Analog Frontend PCB v1.3
2017-08-02 resize board v2.0
    replace through hole parts, change board to 1*2
    [Analog_Frontend.kicad_pcb, Analog_Frontend.sch]
2017-09-29 Analog Board V2.1
    [Analog_Frontend.kicad_pcb, Analog_Frontend.sch]
2017-09-29 Fixed 5V net label in schematic
    [Analog_Frontend.sch]
2017-09-29 Added decoupling capacitors and right angle connector footprints
    [Analog_Frontend.kicad_pcb, Analog_Frontend.sch]
2017-10-02 2。1 modified Oct.1
    [Analog_Frontend.kicad_pcb]
2017-10-02 Updated silkscreen labels
    [Analog_Frontend.kicad_pcb, Analog_Frontend.sch]
2017-10-02 Fixed footprint for edge-mounted SMA connector so that the copper is no longer covered by solder mask.
    [Analog_Frontend.kicad_pcb, Analog_Frontend.sch]
2017-10-02 Updated labels and generated Gerber files for v2.1b
    [Analog_Frontend-B.Cu.gbr, Analog_Frontend-B.Fab.gbr, Analog_Frontend-B.Mask.gbr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]
2017-10-19 Analog BOM & Nucleo pins added
    [Analog_Frontend.kicad_pcb]
2017-11-02 added inductor & res
    [Analog_Frontend.kicad_pcb, Analog_Frontend.sch]
2017-11-03 inducer placed
    [Analog_Frontend.kicad_pcb]
2017-11-03 gerber files
    [Analog_Frontend-B.Cu.gbr, Analog_Frontend-B.Fab.gbr, Analog_Frontend-B.Mask.gbr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]
2017-11-03 fixed 0805
    [Analog_Frontend-B.Cu.gbr, Analog_Frontend-B.Fab.gbr, Analog_Frontend-B.Mask.gbr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]
2017-11-07 Fixed rotation of SOT-23 footprint for Q2
    [Analog_Frontend.sch]
2017-11-07 Q2 footprint change, connect ground plane
    [Analog_Frontend.sch]
2017-12-01 Retroactively fixed v2.2_op1 label and updated component 3D orientations for KiCad v4.0.7
    [Analog_Frontend.kicad_pcb]
